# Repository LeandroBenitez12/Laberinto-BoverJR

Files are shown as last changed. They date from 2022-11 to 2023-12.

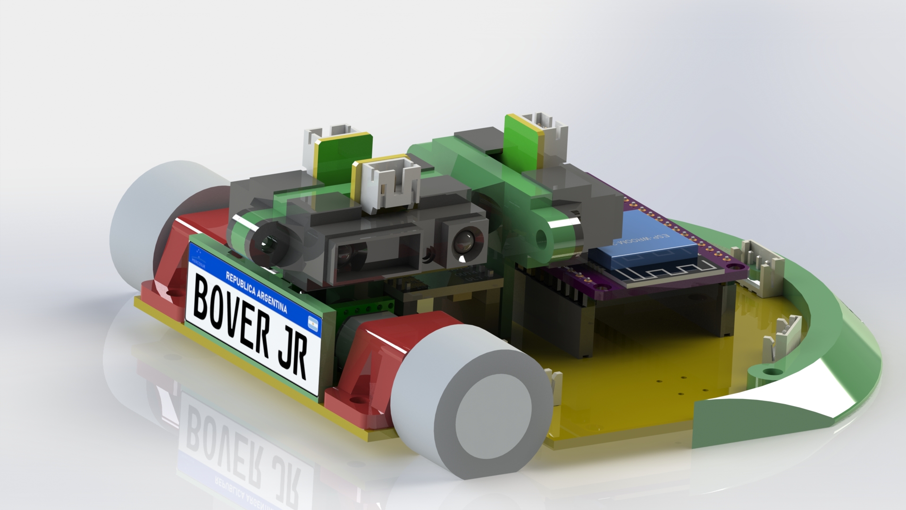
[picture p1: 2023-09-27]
Design 3D/2022 - Bover JR/RenderB.JPG

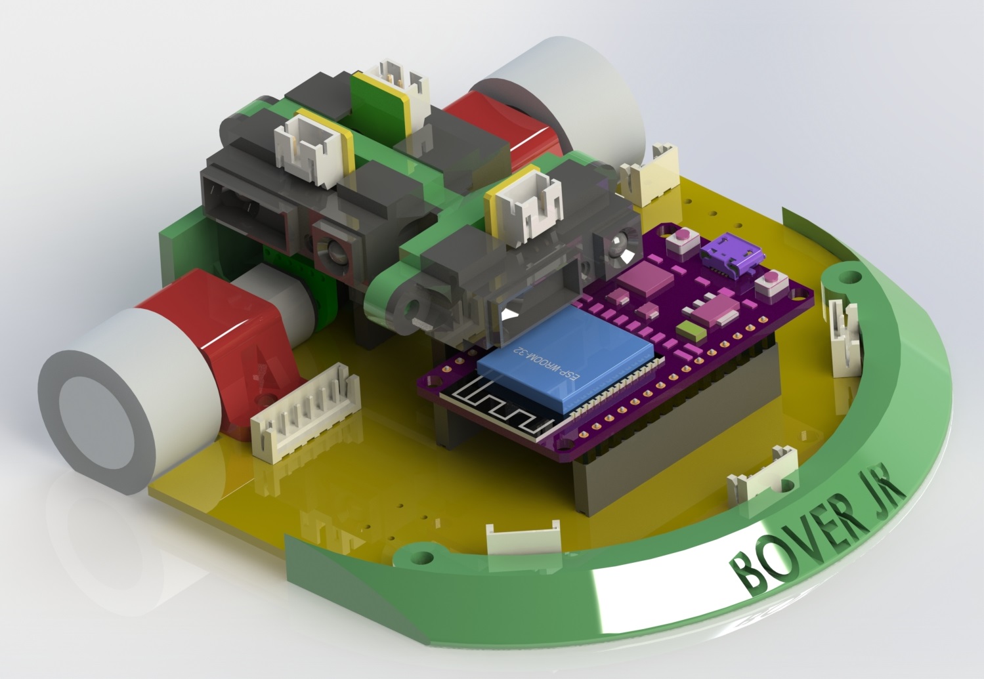
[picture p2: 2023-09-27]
Design 3D/2022 - Bover JR/Render.JPG

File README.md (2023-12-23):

# Robot en Desarrollo para la Resolución de Laberintos 🚧



Laberinto BoverJR 

<a href="https://www.pcbway.com/project/shareproject/Bover_JR_Maze_Robot_1de85bd7.html">PCB from PCBWay</a>

## Descripción del Proyecto

Este repositorio contiene el código y los recursos utilizados para el desarrollo de un robot resolvente de laberintos, creado por Leandro Benitez, Ezequiel Sierra iniciado en 2022 acompañado de nuestro Profesor Ing. Bustos Mariano en el "Industrial de Temperley" ,como parte de un emocionante proyecto para la resolución autónoma de laberintos y la participacion competitiva a nivel nacional en la LNR Argentina. Durante el proceso de creación, hemos estado trabajando arduamente para implementar algoritmos de búsqueda, controladores PID, y trabajar con sensores Sharp y la programación en un microcontrolador ESP32 con el entorno Arduino. También hemos diseñado y creado nuestras propias librerías específicas para el robot, además de experimentar con la utilización de máquinas de estados y Programación orientada a Objetos para lograr un funcionamiento eficiente y preciso.
Actualmente nos encontramos Sponsoreados por PCBWAY.COM donde diseñamos la nueva Version de Bover JR y esperamos competir durante 2023 y 2024 en la LNR , quiero agradecer a **PCBWAY** por financiar el PCB!!!

## Características del Proyecto en Desarrollo

- **Resolución autónoma de laberintos:** Estamos trabajando para permitir que el robot navegue y encuentre la salida de un laberinto sin intervención externa y en el menor tiempo posible.
- **Algoritmos de búsqueda:** Hemos comenzado a implementar diferentes algoritmos de búsqueda para dotar al robot de la capacidad de tomar decisiones inteligentes mientras explora el laberinto.
- **Controladores PID:** Utilizamos controladores PID para mejorar la precisión y estabilidad del robot al seguir una trayectoria y evitar desviaciones indeseadas.
- **Sensores Sharp:** Integración de sensores Sharp para detectar obstáculos y evitar colisiones durante el recorrido del laberinto.
- **ESP32 y Arduino:** El robot se basa en un ESP32 programado con el entorno Arduino, lo que nos brindó flexibilidad y recursos para desarrollar un sistema eficiente y la utilización de Bluetooth para debugear.
- **Librerías personalizadas:** Creamos librerías específicas para nuestro robot, lo que facilitó el manejo y organización del código.

## Estructura del Repositorio

- **/Software:** Aquí se encuentran los códigos que estuvimos trabajando en el laberinto con sus librerías.
- **/Design 3D:** Aqui se encuentran los 3D diseñados para el robot Bover JR 

## Cómo Contribuir

¡Valoramos cualquier contribución que puedas brindar para mejorar nuestro proyecto! Si deseas colaborar, sugerir mejoras o corregir problemas, sigue estos pasos:

1. Haz un fork de este repositorio y clona tu copia localmente.
2. Realiza los cambios y mejoras en tu rama, incluso si es para sugerir posibles soluciones o nuevas ideas.
3. Asegúrate de agregar o actualizar la documentación con tus contribuciones.
4. Realiza un pull request a nuestra rama principal para que podamos revisar y considerar tus aportes.

## Contacto

Nos encantaría recibir tus comentarios, sugerencias y cualquier tipo de feedback que nos ayude a mejorar nuestro proyecto. Si deseas ponerte en contacto con nosotros, no dudes en escribirnos a:

- Leandro Benitez: leandrobenitezz2004@gmail.com
- Empresa : bovergroup@gmail.com

## Sigue actualizado al proyecto siguiendonos en: 
<p align="left">
<a href="https://www.linkedin.com/in/leandro-benitez-995299211/" target="blank">leandrobenitez</a>
<a href="https://www.instagram.com/bovergroup/" target="blank">leandrobenitez</a>
<a href="https://www.tiktok.com/@bovergroup" target="blank">tiktok</a>
<a href="https://www.youtube.com/channel/UCQPRyj8CMgbOlkj3WffF_tw" target="blank">youtube</a>
</p>

## Agradecimientos

Queremos expresar nuestro agradecimiento a todas las personas que nos han brindado apoyo y colaboración en este proyecto, especialmente a **PCBWAY.COM** por sponsorear este proyecto. ¡Sin su ayuda, no habríamos llegado tan lejos en nuestro desarrollo!

Laberinto BoverJR
Laberinto BoverJR
Laberinto BoverJR
Laberinto BoverJR
Laberinto BoverJR




## Videos

https://github.com/LeandroBenitez12/Laberinto-BoverJR/assets/108737751/4792c012-6e11-466b-b290-4252d44b76c1

https://github.com/LeandroBenitez12/Laberinto-BoverJR/assets/108737751/9e88a07d-3f39-4b07-be96-34b641f0b9c9

https://github.com/LeandroBenitez12/Laberinto-BoverJR/assets/108737751/d4477cc3-5138-43af-baba-faa490c5ad7a

Estamos entusiasmados con los avances que hemos logrado hasta el momento, pero reconocemos que aún hay mucho trabajo por delante. Apreciamos tu comprensión y paciencia mientras continuamos mejorando y refinando nuestro robot resolvente de laberintos. Puedes seguir actualizado al proyecto siguiendonos en nuestras redes sociales:
🤖🏆

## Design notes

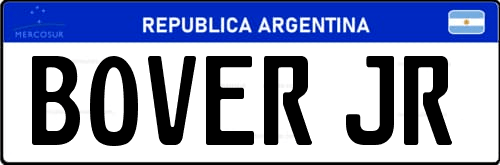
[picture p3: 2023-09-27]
Design 3D/2022 - Bover JR/gARG1.png

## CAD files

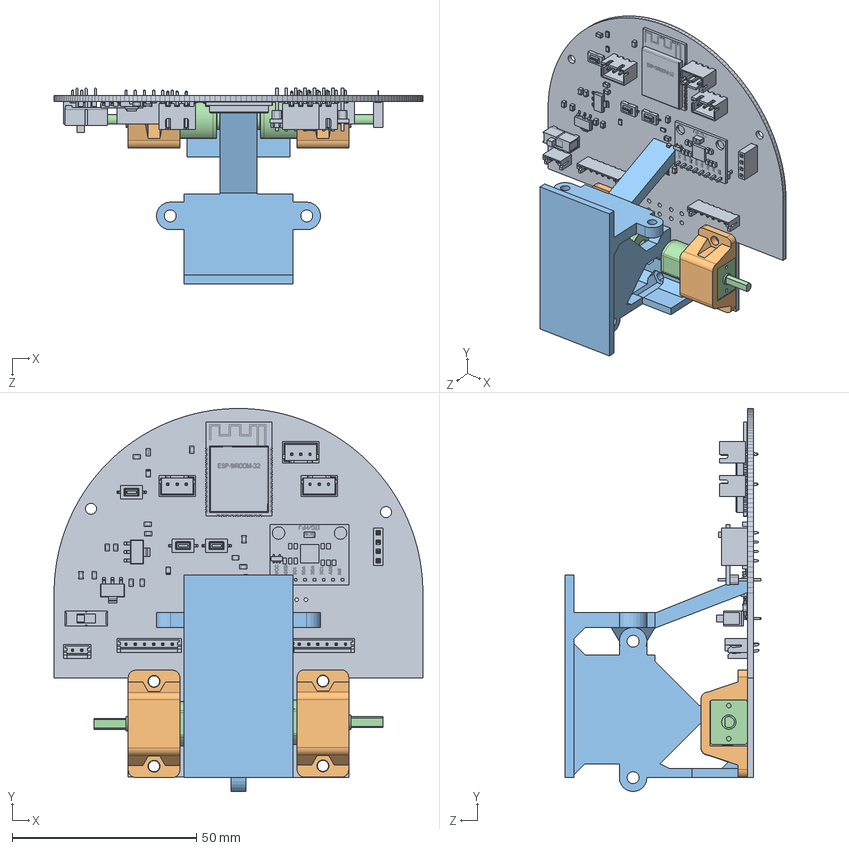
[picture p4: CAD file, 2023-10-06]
Design 3D/2023 - Bover JR/BoverJr_PCBWAY.SLDASM
100.0 x 103.8 x 53.2 mm
BoverJr_PCBWAY_pcb
Soporte_Motor_Pololu_negro_2023 x 2
Soporte_Sharp_Negro_2023
Micro-Motor-Pololu x 2

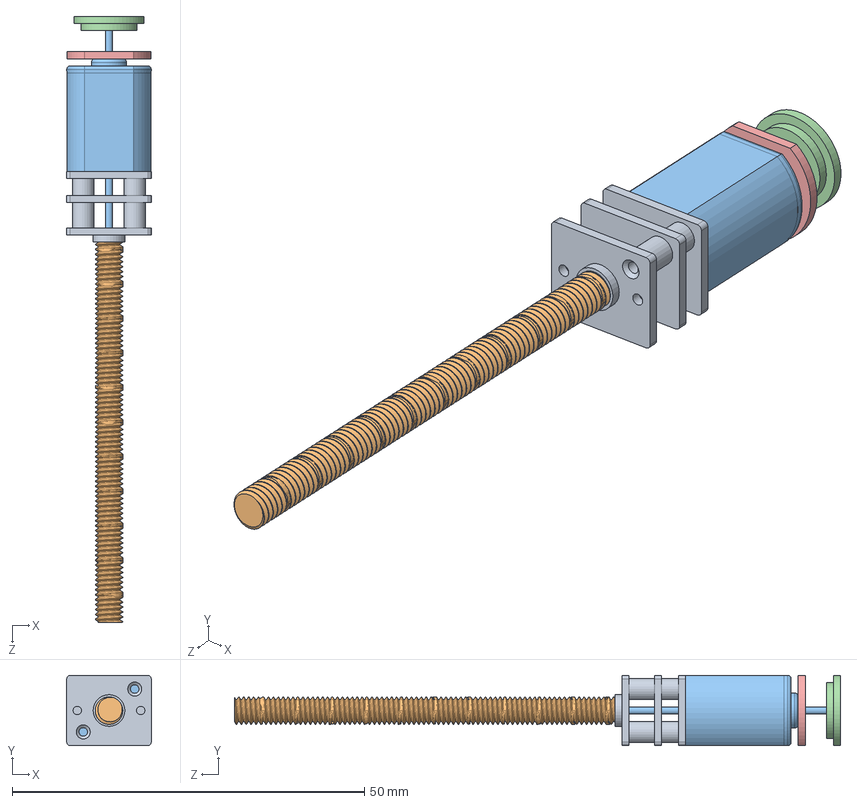
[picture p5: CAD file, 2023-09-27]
Design 3D/2022 - Bover JR/n20 encoder v2..SLDASM
12.0 x 10.0 x 86.0 mm
gearbox.step
threaded rod.step
n20 motor.step
magnet.step
encoder.step

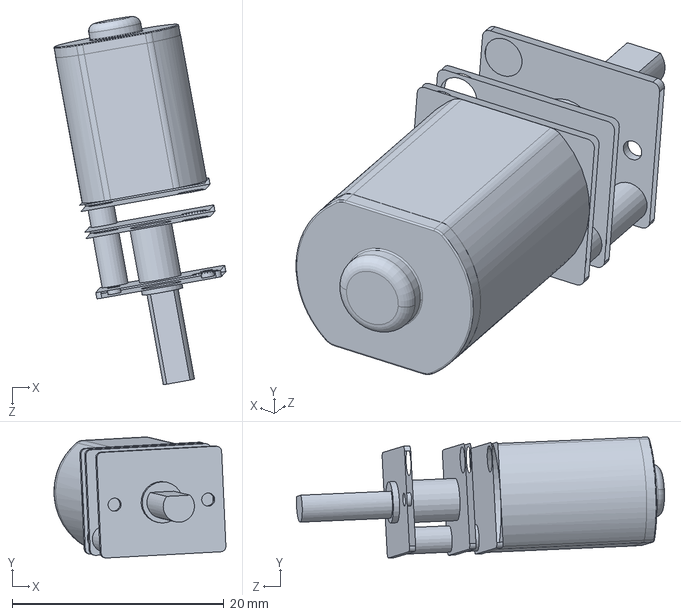
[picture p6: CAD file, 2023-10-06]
Design 3D/2022 - Bover JR/Micro-Motor-Pololu.SLDPRT
16.2 x 11.4 x 34.8 mm

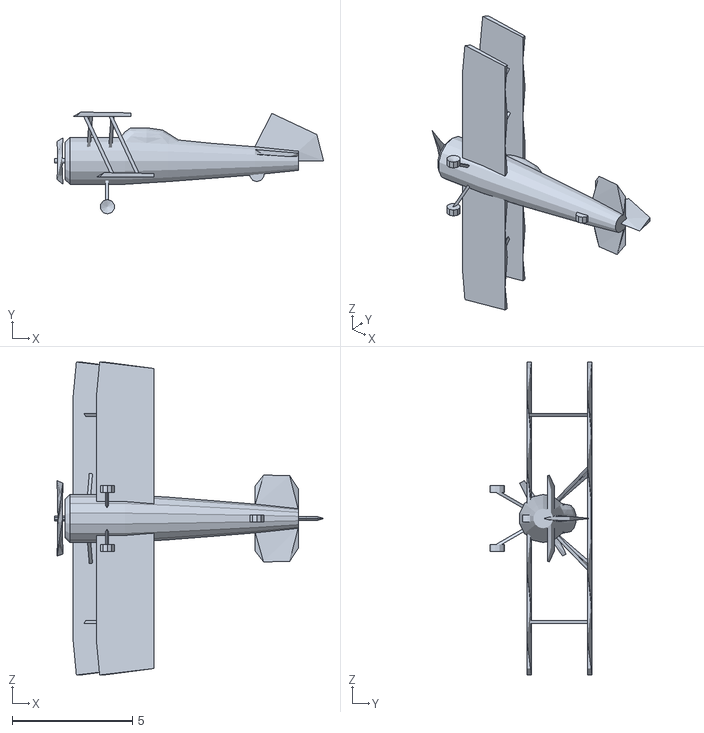
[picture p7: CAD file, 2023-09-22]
Software/Librerias/mpu6050-master/examples/MPU6050_DMP6_using_DMP_V6v12/MPUplane/data/biplane.obj
11.2 x 4.23 x 13.0

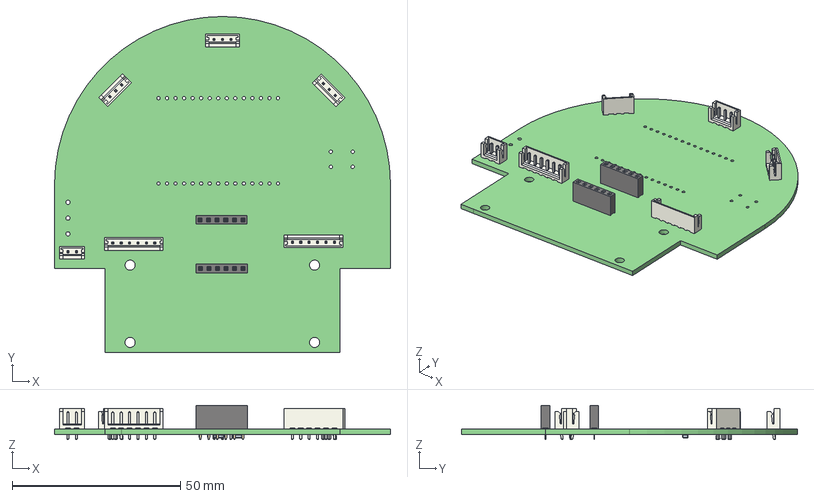
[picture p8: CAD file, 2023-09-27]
Design 3D/2022 - Bover JR/lab_V3.step
100.0 x 100.0 x 10.2 mm
lab_V3 PCB

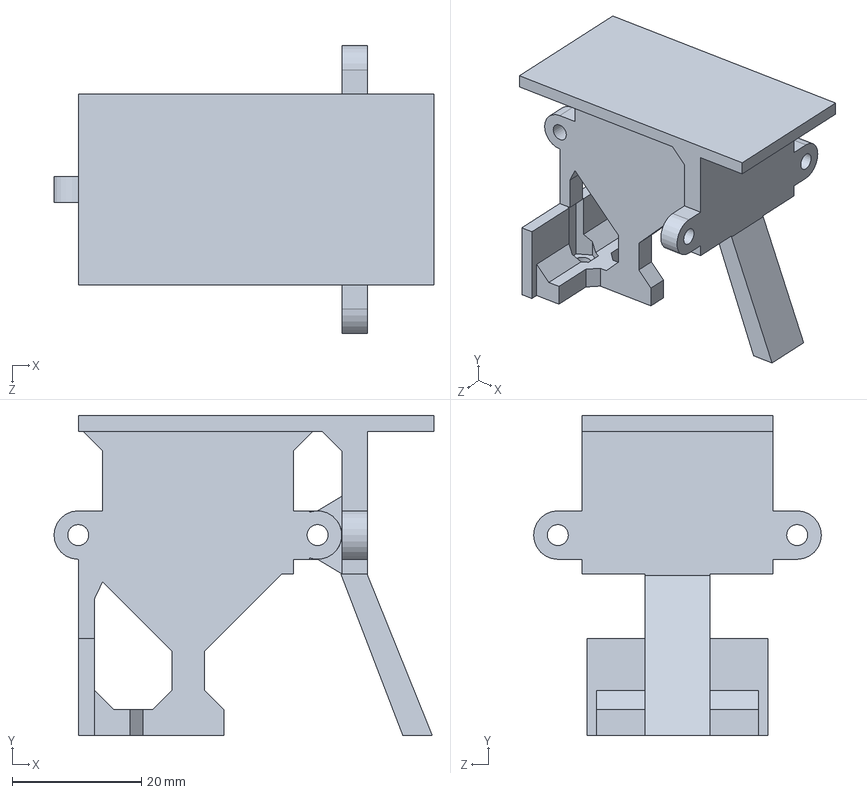
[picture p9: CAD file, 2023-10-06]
Design 3D/2023 - Bover JR/Soporte_Sharp_Negro_2023.SLDPRT
58.8 x 49.5 x 44.5 mm

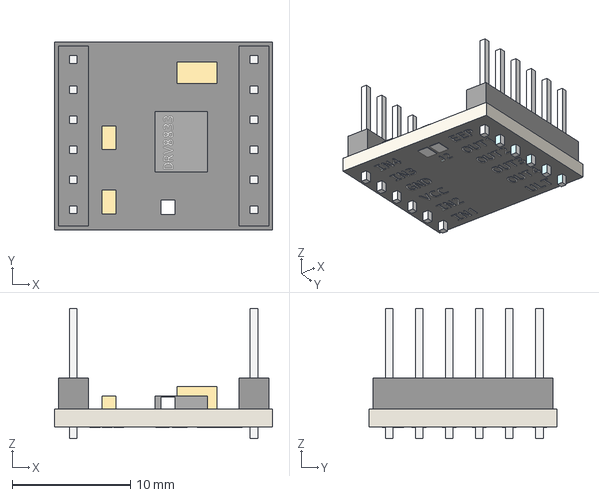
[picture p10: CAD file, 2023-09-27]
Design 3D/2022 - Bover JR/HBridgeDRV8833.step
18.4 x 15.9 x 11.0 mm

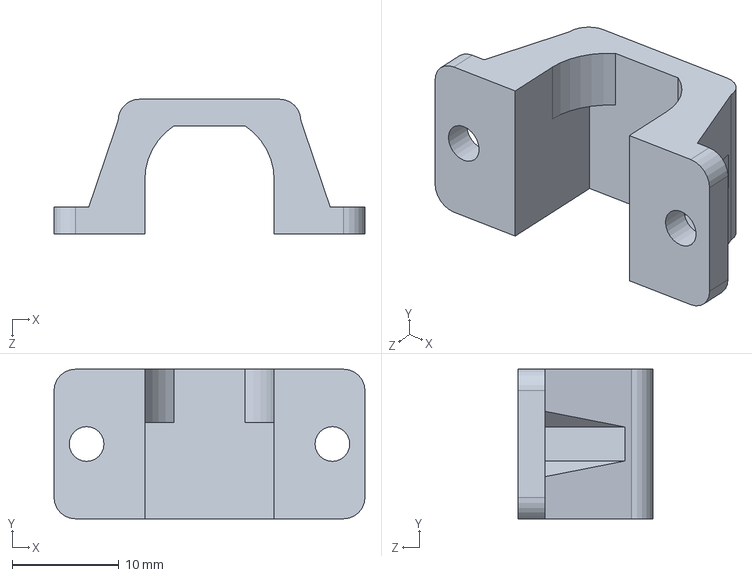
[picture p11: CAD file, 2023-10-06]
Design 3D/2023 - Bover JR/Soporte_Motor_Pololu_negro_2023.SLDPRT
29.1 x 14.0 x 12.6 mm

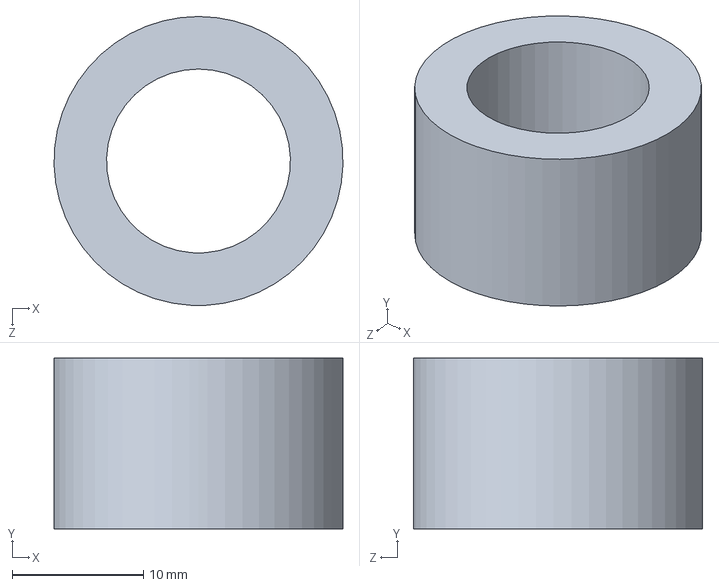
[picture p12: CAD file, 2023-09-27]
Design 3D/2022 - Bover JR/Cubierta_D22d14h13.SLDPRT
22.0 x 13.0 x 22.0 mm

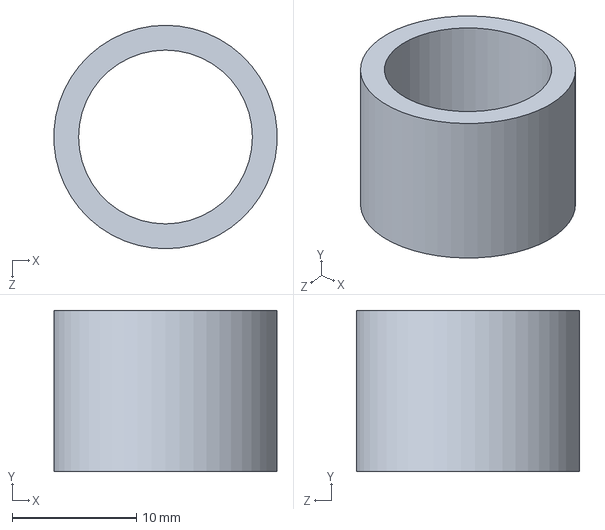
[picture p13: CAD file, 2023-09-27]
Design 3D/2022 - Bover JR/Cubierta_D18d14h13.SLDPRT
18.0 x 13.0 x 18.0 mm

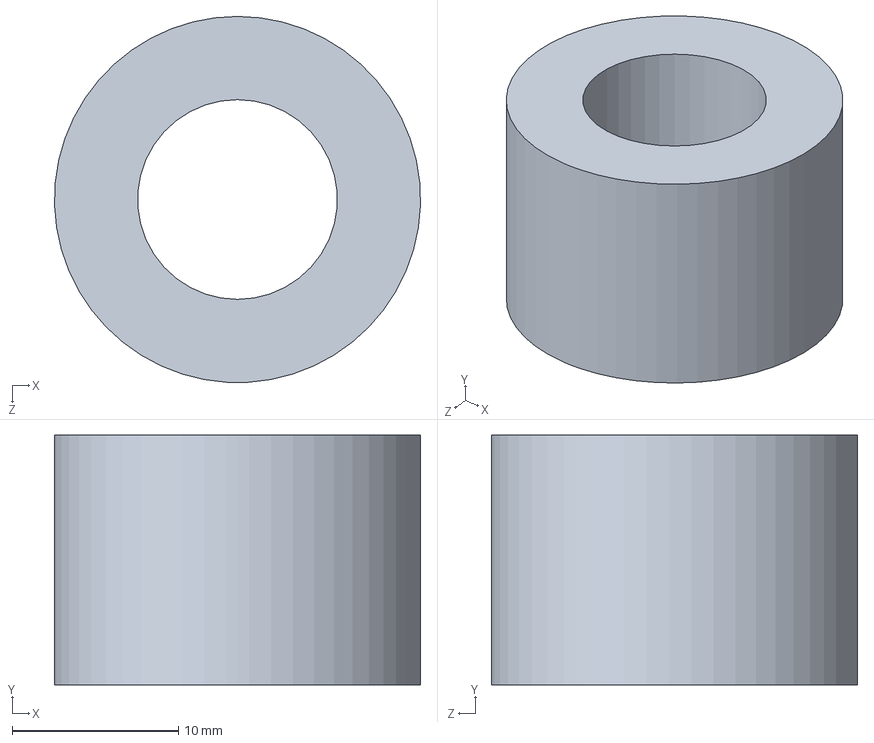
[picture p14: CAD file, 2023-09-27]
Design 3D/2022 - Bover JR/Cubierta.SLDPRT
22.0 x 15.0 x 22.0 mm

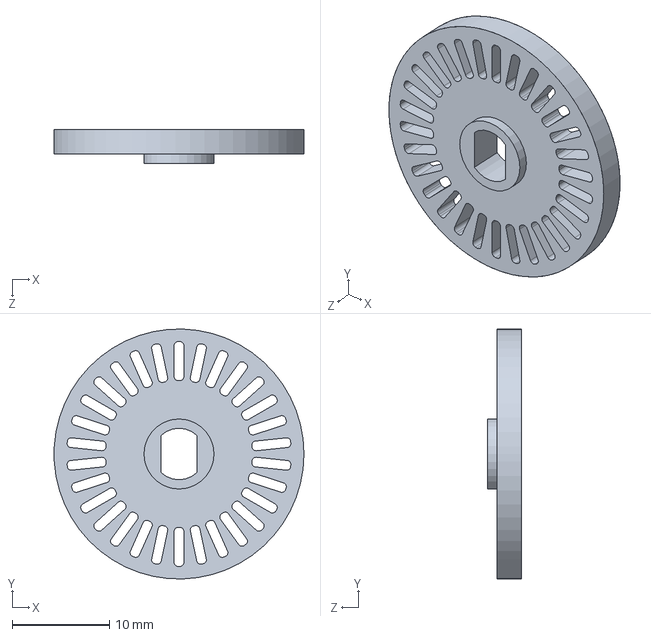
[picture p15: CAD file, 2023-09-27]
Design 3D/2022 - Bover JR/RuedaEncoder30Slot.SLDPRT
25.7 x 25.7 x 3.50 mm

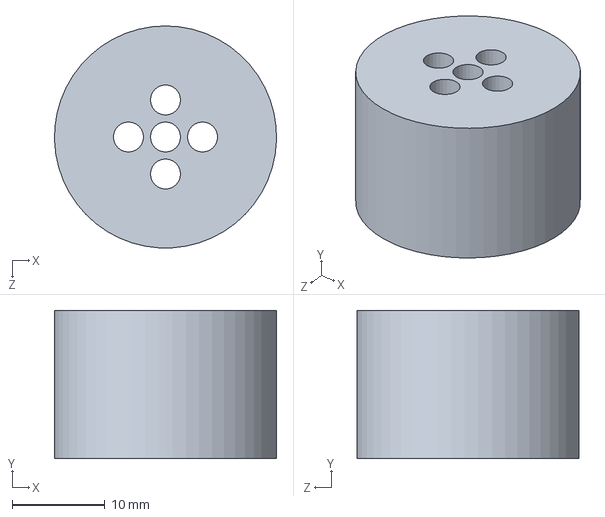
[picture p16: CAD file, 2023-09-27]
Design 3D/2022 - Bover JR/Molde_D22d14h13.SLDPRT
24.0 x 16.0 x 24.0 mm

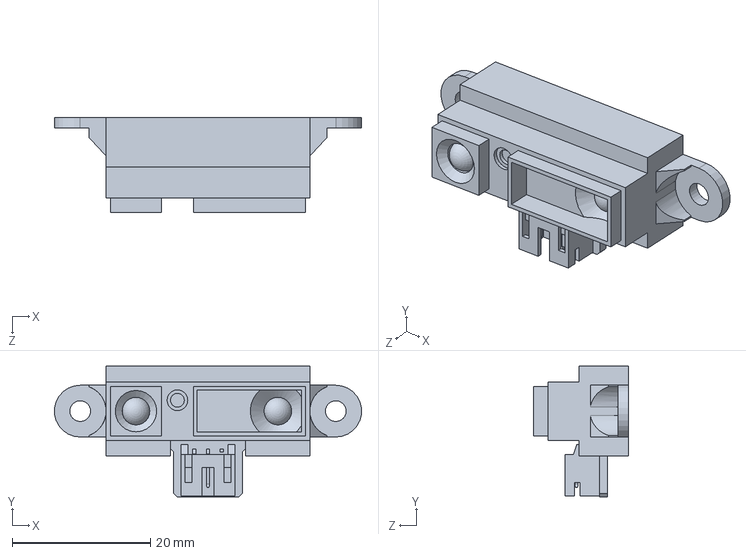
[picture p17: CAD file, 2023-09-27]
Design 3D/2022 - Bover JR/Sensor_Sharp_Corto.SLDPRT
44.4 x 18.9 x 13.7 mm

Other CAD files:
Design 3D/2022 - Bover JR/Soporte_Motor_Pololu.SLDPRT
Design 3D/2022 - Bover JR/Pololu Magnetic Encoder.SLDPRT
Design 3D/2022 - Bover JR/Llanta_3D_V2.SLDPRT
Design 3D/2022 - Bover JR/ESP_32_30Pins.SLDPRT
Design 3D/2022 - Bover JR/Llanta_MiniSumoV1.SLDPRT
Design 3D/2022 - Bover JR/Molde_D22d14h13.STL
Design 3D/2022 - Bover JR/Pololu Magnetic Encoder #1523.SLDPRT
Design 3D/2022 - Bover JR/RuedaEncoder30Slot.STL
Design 3D/2022 - Bover JR/SoporteSharps.SLDPRT
Design 3D/2022 - Bover JR/SoporteSharps.STL
Design 3D/2022 - Bover JR/Soporte_Motor_Pololu.STL
Design 3D/2022 - Bover JR/lab_V3.SLDASM
Design 3D/2022 - Bover JR/n20 encoder v2.SLDPRT
Design 3D/2022 - Bover JR/soporte_piso.SLDPRT
Design 3D/2023 - Bover JR/Soporte_Motor_Pololu_negro_2023.STL
Design 3D/2023 - Bover JR/Soporte_Sharp_Negro_2023.STL

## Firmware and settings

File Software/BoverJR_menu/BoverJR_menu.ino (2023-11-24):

// libreries
#include <PID.h>
#include <EngineController.h>
#include <DistanceSensors.h>
#include <Button.h>
#include "BluetoothSerial.h"
#include "I2Cdev.h"
#include "MPU6050_6Axis_MotionApps20.h"

// I2C
#if I2CDEV_IMPLEMENTATION == I2CDEV_ARDUINO_WIRE
#include "Wire.h"
#endif

// BLUETOOH
#if !defined(CONFIG_BT_ENABLED) || !defined(CONFIG_BLUEDROID_ENABLED)
#error Bluetooth is not enabled! Please run `make menuconfig` to and enable it
#endif
BluetoothSerial SerialBT;

// DEBUG
#define DEBUG_BUTTON 0
#define DEBUG_STATUS 0
#define DEBUG_SENSORS 0
#define DEBUG_PID 0
#define DEBUG_EJE_Z 0
// TICKS DEBUG
#define TICK_DEBUG_ALL 500
unsigned long currentTimeDebugAll = 0;

// PINOUT
// Motores
#define PIN_RIGHT_ENGINE_IN1 27
#define PIN_RIGHT_ENGINE_IN2 26
#define PIN_LEFT_ENGINE_IN1 19
#define PIN_LEFT_ENGINE_IN2 18
#define PWM_CHANNEL_RIGHT_IN1 1
#define PWM_CHANNEL_RIGHT_IN2 2
#define PWM_CHANNEL_LEFT_IN1 3
#define PWM_CHANNEL_LEFT_IN2 4

// Sharps
#define PIN_SHARP_RIGHT 25
#define PIN_SHARP_LEFT 35
#define PIN_SHARP_FRONT 33
float rightDistance;
float leftDistance;
float frontDistance;
#define PARED_ENFRENTE 10
#define PARED_COSTADO_PASILLO 18
#define NO_HAY_PARED 24
#define NO_HAY_PARED_ENFRENTE 24

// MPU
#define INTERRUPT_PIN 4
#define MARGEN 5
#define POSITIVE_ANGLE_MAX 180
#define RIGHT_LIMIT_NEG -180
unsigned long currentTimewhileZ;
float gyroZ;

// Boton
#define PIN_BUTTON_START 32
bool stateStartButton = 0;

// MENU variables
#define VALUE_5 5     // valor 5 para aumentar/disminuir velocidad
#define VALUE_0_1 0.1 // valor 0.1 para aumentar/disminuir PID
bool parar_motores = false;
bool iniciarRobot = false;
bool walltofollow = false;
unsigned long currentTimeMenu = 0;

// veocidades motores pwm
#define SPEED_TURN_LOW 90
#define ENTRAR_EN_PASILLO 300
#define OMITIR_BIFURCACION 600
#define MAX_SPEED 255
int averageSpeedRight = 140; // velocidad inicial
int averageSpeedLeft = 150;  // velocidad inicial + 10
int speedRightPID;
int speedLeftPID;
int speedRightPID2;
int speedLeftPID2;

// Constantes y variables pid
unsigned long currentTimePID = 0;
#define TICK_PID 1
double kp = 3;
double kd = 0.6;
double ki = 0.0;
double setPoint = 0.0;
double gananciaPID = 0;
double input = 0;

// variables pid2
double kp2 = 0;
double kd2 = 0;
double ki2 = 0.0;
double setPoint2 = 0;
double gananciaPID2;
double TICK_PID2 = 1.0;

unsigned long currentTimeStop = 0;
#define TICK_STOP 1000
#define TICK_CENTRAR 500
// enum state
enum movement
{
  STANDBY,
  CONTINUE,
  STOP,
  RIGHT_TURN,
  LEFT_TURN,
  FULL_TURN,
  POST_TURN_FULL,
  POST_TURN_MIDDLE,
  ANT_TURN
};
int movement = STANDBY;

// INSTANCIANDO OBJETOS
IEngine *leftEngine = new Driver_DRV8825(PIN_RIGHT_ENGINE_IN1, PIN_RIGHT_ENGINE_IN2, PWM_CHANNEL_RIGHT_IN1, PWM_CHANNEL_RIGHT_IN2);
IEngine *rightEngine = new Driver_DRV8825(PIN_LEFT_ENGINE_IN1, PIN_LEFT_ENGINE_IN2, PWM_CHANNEL_LEFT_IN1, PWM_CHANNEL_LEFT_IN2);
EngineController *Bover = new EngineController(rightEngine, leftEngine);
Isensor *SharpRight = new Sharp_GP2Y0A21(PIN_SHARP_RIGHT);
Isensor *SharpLeft = new Sharp_GP2Y0A21(PIN_SHARP_LEFT);
Isensor *SharpFront = new Sharp_GP2Y0A21(PIN_SHARP_FRONT);
Pid *PID = new Pid(kp, kd, ki, setPoint, TICK_PID);
Pid *PID2 = new Pid(kp2, kd2, ki2, setPoint2, TICK_PID2);
Button *buttonStart1 = new Button(PIN_BUTTON_START);
MPU6050 mpu;

// MPU control/status vars
bool dmpReady = false;  // set true if DMP init was successful
uint8_t mpuIntStatus;   // holds actual interrupt status byte from MPU
uint8_t devStatus;      // return status after each device operation (0 = success, !0 = error)
uint16_t packetSize;    // expected DMP packet size (default is 42 bytes)
uint16_t fifoCount;     // count of all bytes currently in FIFO
uint8_t fifoBuffer[64]; // FIFO storage buffer
Quaternion q;           // [w, x, y, z]
VectorInt16 aa;         // [x, y, z]
VectorInt16 aaReal;     // [x, y, z]
VectorInt16 aaWorld;    // [x, y, z]
VectorFloat gravity;    // [x, y, z]
float ypr[3];           // [yaw, pitch, roll]
volatile bool mpuInterrupt = false;

void dmpDataReady()
{
  mpuInterrupt = true;
}

void mpuSetup()
{
// join I2C bus (I2Cdev library doesn't do this automatically)
#if I2CDEV_IMPLEMENTATION == I2CDEV_ARDUINO_WIRE
  Wire.begin();
  Wire.setClock(400000); // 400kHz I2C clock. Comment this line if having compilation difficulties
#elif I2CDEV_IMPLEMENTATION == I2CDEV_BUILTIN_FASTWIRE
  Fastwire::setup(400, true);
#endif

  // Iniciar MPU6050
  SerialBT.println(F("Initializing I2C devices..."));
  mpu.initialize();
  pinMode(INTERRUPT_PIN, INPUT);

  // Comprobar  conexion
  SerialBT.println(F("Testing device connections..."));
  SerialBT.println(mpu.testConnection() ? F("MPU6050 connection successful") : F("MPU6050 connection failed"));

  // Iniciar DMP
  SerialBT.println(F("Initializing DMP..."));
  devStatus = mpu.dmpInitialize();

  // Valores de calibracion
  mpu.setXGyroOffset(60);
  mpu.setYGyroOffset(49);
  mpu.setZGyroOffset(-69);
  mpu.setZAccelOffset(1046);

  // Activar DMP
  if (devStatus == 0)
  {
    SerialBT.println(F("Enabling DMP..."));
    mpu.setDMPEnabled(true);

    // Activar interrupcion
    attachInterrupt(digitalPinToInterrupt(INTERRUPT_PIN), dmpDataReady, RISING);
    mpuIntStatus = mpu.getIntStatus();

    SerialBT.println(F("DMP ready! Waiting for first interrupt..."));
    dmpReady = true;

    // get expected DMP packet size for later comparison
    packetSize = mpu.dmpGetFIFOPacketSize();
  }
  else
  {
    // ERROR!
    // 1 = initial memory load failed
    // 2 = DMP configuration updates failed
    // (if it's going to break, usually the code will be 1)
    SerialBT.print(F("DMP Initialization failed (code "));
    SerialBT.print(devStatus);
    SerialBT.println(F(")"));
  }
}
// MPU LOOP
float mpuLoop()
{
  // Si fallo al iniciar, parar programa
  // if (!dmpReady)
  // return;
  // Ejecutar mientras no hay interrupcion
  while (!mpuInterrupt && fifoCount < packetSize)
  {
  // AQUI EL RESTO DEL CODIGO DE TU PROGRRAMA
  }
  mpuInterrupt = false;
  mpuIntStatus = mpu.getIntStatus();

  // Obtener datos del FIFO
  fifoCount = mpu.getFIFOCount();

  // Controlar overflow
  if ((mpuIntStatus & 0x10) || fifoCount == 4096)
  {
    mpu.resetFIFO();
    // SerialBT.println(F("FIFO overflow!"));
  }
  else if (mpuIntStatus & 0x02)
  {
    // wait for correct available data length, should be a VERY short wait
    while (fifoCount < packetSize)
      fifoCount = mpu.getFIFOCount();

    // read a packet from FIFO
    mpu.getFIFOBytes(fifoBuffer, packetSize);

    // track FIFO count here in case there is > 1 packet available
    // (this lets us immediately read more without waiting for an interrupt)
    fifoCount -= packetSize;

    // MMostrar Yaw, Pitch, Roll
    mpu.dmpGetQuaternion(&q, fifoBuffer);
    mpu.dmpGetGravity(&gravity, &q);
    mpu.dmpGetYawPitchRoll(ypr, &q, &gravity);
    float gz;
    return gz = ypr[0] * 180 / M_PI;
    delay(1);
  }
}
// LECTURA SENSORS
void SensorsRead()
{
  frontDistance = SharpFront->SensorRead();
  rightDistance = SharpRight->SensorRead();
  leftDistance = SharpLeft->SensorRead();
}

// IMPRIMIR EN BLUETOOH
void printButton()
{
  SerialBT.print("Button Start: ");
  SerialBT.println(stateStartButton);
}

void printPID()
{
  if (millis() > currentTimePID + TICK_DEBUG_ALL)
  {
    currentTimePID = millis();
    SerialBT.println("");
    SerialBT.print("Ganancia PID 1: ");
    SerialBT.println(gananciaPID);
    // SerialBT.print("Ganancia PID 2: ");
    // SerialBT.println(gananciaPID2);
    SerialBT.print("speedRight: ");
    SerialBT.print(speedRightPID);
    SerialBT.print(" || speedLeft: ");
    SerialBT.println(speedLeftPID);
    SerialBT.println("");
  }
}

void printEjeZ()
{
  SerialBT.print("Eje Z:  ");
  SerialBT.print(gyroZ);
}

void printSensors()
{
  SerialBT.print("LeftDistance: ");
  SerialBT.println(leftDistance);
  SerialBT.print("frontDistance: ");
  SerialBT.println(frontDistance);
  SerialBT.print(" || rightDistance: ");
  SerialBT.println(rightDistance);
}

void printOptions()
{
  // clean the serial
  for (int i = 0; i < 5; i++)
  {
    SerialBT.println("");
  }
  SerialBT.println("Configuracion Actual:");

  SerialBT.print("A+/B- KP = ");
  SerialBT.println(kp);

  SerialBT.print("C+/D- KP2 = ");
  SerialBT.println(kp2);

  SerialBT.print("E+/F- KD = ");
  SerialBT.println(kd);

  SerialBT.print("G+/H- KD2 = ");
  SerialBT.println(kd2);

  SerialBT.print("I+/J- - leftSpeed = ");
  SerialBT.println(averageSpeedLeft);

  SerialBT.print("K+/L- - rightLeft = ");
  SerialBT.println(averageSpeedRight);

  SerialBT.print("N - Wall to follow = ");
  String state = "";
  if (walltofollow == true)
    state = "Right";
  else
    state = "Left";
  SerialBT.println(state);

  SerialBT.print("P - Motor parado = ");
  SerialBT.println(parar_motores);

  SerialBT.println("Y - DEBUGEAR ROBOT ");

  SerialBT.println("Z - INICIAR ROBOT ");

  for (int i = 0; i < 5; i++)
  {
    SerialBT.println("");
  }
}
// GIROS 90º Y 180º
void turnRight()
{
  SerialBT.println("  entro right  ");
  do
  {
    SensorsRead();
    Bover->Right(SPEED_TURN_LOW, SPEED_TURN_LOW);
  } while ( frontDistance < 28);
  SerialBT.println("  sali right  ");
  movement = POST_TURN_MIDDLE;
}

void turnLeft()
{
  SerialBT.println("  entro left  ");
  do
  {
    SensorsRead();
    Bover->Left(SPEED_TURN_LOW, SPEED_TURN_LOW);
  } while ( frontDistance < 28);
  SerialBT.println("  sali left  ");
  movement = POST_TURN_MIDDLE;
}

void fullTurn()
{
  SerialBT.println("  entro full  ");
  do
  {
    SensorsRead();
    Bover->Right(SPEED_TURN_LOW, SPEED_TURN_LOW);
  } while ( frontDistance < 28);
  SerialBT.println("  sali FULL  ");
  movement = CONTINUE;
}

void postTurnFull()
{
  Bover->Forward(averageSpeedRight, averageSpeedLeft);
  delay(OMITIR_BIFURCACION);
}
void postTurnMiddle()
{
  Bover->Forward(averageSpeedRight, averageSpeedLeft);
  delay(ENTRAR_EN_PASILLO);
}

void antTurn()
{
  Bover->Forward(averageSpeedRight, averageSpeedLeft);
  delay(TICK_CENTRAR);
}

void menuBT()
{
  if (SerialBT.available())
  {
    char option = SerialBT.read();
    switch (option)
    {
    case 'M':
    {
      printOptions();
      break;
    }
    case 'A':
    {
      kp += VALUE_0_1;
      SerialBT.println("");
      printOptions();
      SerialBT.println("");
      break;
    }
    case 'B':
    {
      kp -= VALUE_0_1;
      SerialBT.println("");
      printOptions();
      SerialBT.println("");
      break;
    }
    case 'C':
    {
      kp2 += VALUE_0_1;
      SerialBT.println("");
      printOptions();
      SerialBT.println("");
      break;
    }
    case 'D':
    {
      kp2 -= VALUE_0_1;
      SerialBT.println("");
      printOptions();
      SerialBT.println("");
      break;
    }
    case 'E':
    {
      kd += VALUE_0_1;
      SerialBT.println("");
      printOptions();
      SerialBT.println("");
      break;
    }
    case 'F':
    {
      kd -= VALUE_0_1;
      SerialBT.println("");
      printOptions();
      SerialBT.println("");
      break;
    }
    case 'G':
    {
      kd2 += VALUE_0_1;
      SerialBT.println("");
      printOptions();
      SerialBT.println("");
      break;
    }
    case 'H':
    {
      kd2 -= VALUE_0_1;
      SerialBT.println("");
      printOptions();
      SerialBT.println("");
      break;
    }
    case 'I':
    {
      averageSpeedLeft = averageSpeedLeft + VALUE_5;

      SerialBT.println("");
      printOptions();
      SerialBT.println("");
      break;
    }
    case 'J':
    {
      averageSpeedLeft = averageSpeedLeft - VALUE_5;
      SerialBT.println("");
      printOptions();
      SerialBT.println("");
      break;
    }
    case 'K':
    {
      averageSpeedRight = averageSpeedRight + VALUE_5;
      SerialBT.println("");
      printOptions();
      SerialBT.println("");
      break;
    }

    case 'L':
    {
      averageSpeedRight -= VALUE_5;
      SerialBT.println("");
      printOptions();
      SerialBT.println("");
      break;
    }
    case 'N':
    {
      walltofollow = true;

      SerialBT.println("");
      printOptions();
      SerialBT.println("");
      break;
    }
    case 'P':
    {
      parar_motores = true;

      SerialBT.println("");
      printOptions();
      SerialBT.println("");
      break;
    }
    case 'Z':
    {
      stateStartButton = true;
      SerialBT.println("");
      printOptions();
      SerialBT.println("");
      break;
    }
    default:
      SerialBT.println("OPCION INCORRECTA ");
      break;
    }
  }
}

void movementLogic()
{
  switch (movement)
  {
  case STANDBY:
  {
    Bover->Stop();
    if (stateStartButton)
    {
      delay(2000);
      movement = CONTINUE;
    }
  }
  break;
  case CONTINUE:
  {
    //float input = leftDistance;
    //if (walltofollow)
    //  input = rightDistance;

    input = rightDistance - leftDistance;
    gananciaPID = PID->ComputePid(input);
    // gananciaPID2 = PID2->ComputePid(input2);
    //  INPUT2 = WALLTOFOLLOW PARA MANTENER LA DISTANCIA A ESA PARED
    //  float input2 = leftDistance;
    //  if (walltofollow == true)
    //  input2 = rightDistance;
    //  gananciaPID2 = PID2->ComputePid(input2);

    if (DEBUG_PID)
      printPID();

    speedRightPID = (averageSpeedRight - (gananciaPID));
    speedLeftPID = (averageSpeedLeft + (gananciaPID));

    // APLICAMOS GANANCIA 1 DEL PID A MOTORES. okey
    // if (walltofollow)
    // {
    //   speedRightPID = (averageSpeedRight - (gananciaPID));
    //   speedLeftPID = (averageSpeedLeft + (gananciaPID));
    // }
    // else
    // {
    //   speedRightPID = (averageSpeedRight + (gananciaPID));
    //   speedLeftPID = (averageSpeedLeft - (gananciaPID));
    // }
    // APLICAMOS GANANCIA 2 DEL PID A MOTORES
    // speedRightPID2 = (speedRightPID + (gananciaPID2));
    // speedLeftPID2 = (speedLeftPID - (gananciaPID2));

    // ESTABLECEMOS LOS LIMITES
    if (speedLeftPID > MAX_SPEED)
    {
      int umbralLeft = (speedLeftPID - MAX_SPEED);
      speedRightPID = speedRightPID - umbralLeft;
      speedLeftPID = MAX_SPEED;
    }

    if (speedRightPID > MAX_SPEED)
    {
      int umbralRight = (speedRightPID - MAX_SPEED);
      speedLeftPID = speedLeftPID - umbralRight;
      speedRightPID = MAX_SPEED;
    }

    if (parar_motores)
    {
      Bover->Stop();
    }
    else
    {
      Bover->Forward(speedRightPID, speedLeftPID);
    }

    if (walltofollow == true)
    {
      if (leftDistance > NO_HAY_PARED && frontDistance > NO_HAY_PARED_ENFRENTE && rightDistance > NO_HAY_PARED)
      {
        movement = ANT_TURN;
      }
      if (leftDistance <= PARED_COSTADO_PASILLO && frontDistance > NO_HAY_PARED_ENFRENTE && rightDistance > NO_HAY_PARED)
      {
        movement = ANT_TURN;
      }
      if (leftDistance > NO_HAY_PARED && frontDistance > NO_HAY_PARED_ENFRENTE && rightDistance <= PARED_COSTADO_PASILLO)
      {
        movement = POST_TURN_FULL;
      }
    }
    else
    {
      if (leftDistance > NO_HAY_PARED && frontDistance > NO_HAY_PARED_ENFRENTE && rightDistance > NO_HAY_PARED)
      {
        movement = ANT_TURN;
      }
      if (leftDistance > NO_HAY_PARED && frontDistance > NO_HAY_PARED_ENFRENTE && rightDistance <= PARED_COSTADO_PASILLO)
      {
        movement = ANT_TURN;
      }
      if (leftDistance <= PARED_COSTADO_PASILLO && frontDistance > NO_HAY_PARED_ENFRENTE && rightDistance > NO_HAY_PARED)
      {
        movement = POST_TURN_FULL;
      }
    }
    if (frontDistance <= PARED_ENFRENTE)
    {
      movement = STOP;
    }
    break;
  }
  case STOP:
  {
    Bover->Stop();
    delay(500);
    if (frontDistance <= PARED_ENFRENTE)
    {
      if (rightDistance > NO_HAY_PARED && leftDistance > NO_HAY_PARED)
      {
        if (walltofollow = true)
        {
          movement = RIGHT_TURN;
        }
        else
        {
          movement = LEFT_TURN;
        }
      }
      else if (rightDistance <= PARED_COSTADO_PASILLO && leftDistance <= PARED_COSTADO_PASILLO)
      {
        movement = FULL_TURN;
      }
      else if (rightDistance > NO_HAY_PARED && leftDistance <= PARED_COSTADO_PASILLO)
      {
        movement = RIGHT_TURN;
      }
      else if (rightDistance <= PARED_COSTADO_PASILLO && leftDistance > NO_HAY_PARED)
      {
        movement = LEFT_TURN;
      }
    }
    else
    {
      movement = CONTINUE;
    }
    break;
  }

  case RIGHT_TURN:
  {
    turnRight();
    break;
  }

  case LEFT_TURN:
  {
    turnLeft();
    break;
  }

  case FULL_TURN:
  {
    fullTurn();
    break;
  }

  case POST_TURN_MIDDLE:
  {
    postTurnMiddle();
    movement = CONTINUE;
    break;
  }

  case POST_TURN_FULL:
  {
    postTurnFull();
    movement = CONTINUE;
    break;
  }
  case ANT_TURN:
  {
    antTurn();
    if (walltofollow == true)
    {
      movement = RIGHT_TURN;
    }
    else
    {
      movement = LEFT_TURN;
    }
  }
  }
}

void printStatus()
{
  String state = "";
  switch (movement)
  {
  case STANDBY:
    state = "STANDBY";
    break;
  case CONTINUE:
    state = "CONTINUE";
    break;
  case STOP:
    state = state = "STOP";
    break;
  case RIGHT_TURN:
    state = "RIGHT TURN";
    break;
  case LEFT_TURN:
    state = "LEFT TURN";
    break;
  case FULL_TURN:
    state = "FULL TURN";
    break;
  case POST_TURN_MIDDLE:
    state = "POST TURN MIDDLE";
    break;
  case POST_TURN_FULL:
    state = "POST TURN FULL";
    break;
  case ANT_TURN:
    state = "ANT TURN ";
    break;
  }
  SerialBT.print("State: ");
  SerialBT.println(state);
}

void printAll()
{
  if (millis() > currentTimeDebugAll + TICK_DEBUG_ALL)
  {
    currentTimeDebugAll = millis();
    if (DEBUG_BUTTON)
      printButton();
    SerialBT.println("");
    if (DEBUG_SENSORS)
      printSensors();
    SerialBT.println("");
    if (DEBUG_STATUS)
      printStatus();
    SerialBT.println("");
    if (DEBUG_EJE_Z)
      printEjeZ();
    SerialBT.println("");
  }
}
void setup()
{
  Serial.begin(115200);
  SerialBT.begin("Bover JR");
  mpuSetup();
}

void loop()
{
  gyroZ = mpuLoop();
  stateStartButton = buttonStart1->GetIsPress();
  SensorsRead();
  if (iniciarRobot == false)
  {
    menuBT();
  }
  if (stateStartButton == true)
  {
    iniciarRobot = true;
  }
  if (iniciarRobot == true)
  {
    movementLogic();
    printAll();
  }
}

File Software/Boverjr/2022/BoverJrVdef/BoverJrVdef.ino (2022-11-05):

#include <PID.h>
#include <Engine.h>
#include <Button.h>
#include <QRE1113.h>
#include <SharpLab.h>
#include "BluetoothSerial.h"


//debug
#define DEBUG 1
#define TICK_DEBUG 400
unsigned long currentTimeDebug = 0;
unsigned long currentTimeDebugSensors = 0;
unsigned long currentTimeDebugPID = 0;

// declaramos pines
// motores
#define PIN_ENGINE_MR1 23
#define PIN_ENGINE_MR2 22
#define PIN_ENGINE_ML1 19
#define PIN_ENGINE_ML2 18

// Button
#define PIN_BUTTON_START 39
bool button_start;

//Sensor final
#define PIN_END_SENSOR 32

//Sharps
#define PIN_SHARP_RIGHT 34
#define PIN_SHARP_LEFT 27
#define PIN_SHARP_FRONT 35
float frontDistance;
float rightDistance;
float leftDistance;
#define MAX_FRONT_DISTANCE 20
#define MAX_SIDE_DISTANCE 12

//encoder 
int interruptPinRight = 26;
int interruptPinLeft = 21;
volatile long rightCont = 0;
volatile long leftCont = 0;
#define TICK_TURN_RIGHT_90 17
#define TICK_TURN_LEFT_90 120
#define TICK_TURN_180 34
#define TICK_POST_TURN 37
#define TICK_ANT_TURN 30
#define TICK_IGNORE_TURN 40

void rightEncRead()
{
    rightCont++;
}

void leftEncRead()
{
    leftCont++;
}

//veocidades motores pwm
int speedRight = 80;
int speedLeft = 80;
int averageSpeed = 80;
int speedTurn = 80;

//variables pid
double kp = 0.175;
double kd = 0;
double setPoint;
float PID1;
double TICK_PID = 50;


#if !defined(CONFIG_BT_ENABLED) || !defined(CONFIG_BLUEDROID_ENABLED)
#error Bluetooth is not enabled! Please run `make menuconfig` to and enable it
#endif

BluetoothSerial SerialBT;

//instancio los objetos
Engine *engineRigh = new  Engine(PIN_ENGINE_MR1, PIN_ENGINE_MR2);
Engine *engineLeft = new Engine(PIN_ENGINE_ML1, PIN_ENGINE_ML2);

Button *start = new Button(PIN_BUTTON_START);

QRE1113 *endSensor = new QRE1113(PIN_END_SENSOR);

Sharp *SharpFront = new Sharp(PIN_SHARP_FRONT);
Sharp *SharpRigh = new Sharp(PIN_SHARP_RIGHT);
Sharp *SharpLeft = new Sharp(PIN_SHARP_LEFT);

Pid *engine = new Pid(kp, kd, setPoint, TICK_PID);

// funciones de los motores
void forward()
{
  engineRigh->SetSpeed(speedRight);
  engineLeft->SetSpeed(speedLeft);
  engineRigh->Forward();
  engineLeft->Forward();
}

void backward()
{
  engineRigh->SetSpeed(speedRight);
  engineLeft->SetSpeed(speedLeft);
  engineRigh->Backward();
  engineLeft->Backward();
}

void left()
{
  engineRigh->SetSpeed(speedRight);
  engineLeft->SetSpeed(speedLeft);
  engineRigh->Forward();
  engineLeft->Backward();
}

void right()
{
  engineRigh->SetSpeed(speedRight);
  engineLeft->SetSpeed(speedLeft);
  engineRigh->Backward();
  engineLeft->Forward();
}

void stop()
{
  engineRigh->SetSpeed(0);
  engineLeft->SetSpeed(0);
  engineRigh->Stop();
  engineLeft->Stop();
}

void turnRight()
{
  rightCont = 0;
  leftCont = 0;
  while(rightCont < TICK_TURN_RIGHT_90 || leftCont < TICK_TURN_RIGHT_90)
  {
    engineRigh->SetSpeed(speedTurn);
    engineLeft->SetSpeed(speedTurn);
    engineRigh->Backward();
    engineLeft->Forward();
  }
}

void turnLeft()
{
  rightCont = 0;
  leftCont = 0;
  while(rightCont < TICK_TURN_LEFT_90 || leftCont < TICK_TURN_LEFT_90)
  {
    engineRigh->SetSpeed(speedTurn);
    engineLeft->SetSpeed(speedTurn);
    engineRigh->Forward();
    engineLeft->Backward();
  }
}

void fulTurn()
{
  rightCont = 0;
  leftCont = 0;
  while(rightCont < TICK_TURN_180 || leftCont < TICK_TURN_180)
  {
    engineRigh->SetSpeed(speedTurn);
    engineLeft->SetSpeed(speedTurn);
    engineRigh->Forward();
    engineLeft->Backward();
  }
}

void antTurn()
{
  rightCont = 0;
  leftCont = 0;
  while(rightCont < TICK_ANT_TURN || leftCont < TICK_ANT_TURN)
  {
    engineRigh->SetSpeed(averageSpeed);
    engineLeft->SetSpeed(averageSpeed);
    engineRigh->Forward();
    engineLeft->Forward();
  }
}

void posTurn()
{
  rightCont = 0;
  leftCont = 0;
  while(rightCont < TICK_POST_TURN || leftCont < TICK_POST_TURN)
  {
    engineRigh->SetSpeed(averageSpeed);
    engineLeft->SetSpeed(averageSpeed);
    engineRigh->Forward();
    engineLeft->Forward();
  }
}

void ignoreTurn()
{
  rightCont = 0;
  leftCont = 0;
  while(rightCont < TICK_IGNORE_TURN || leftCont < TICK_IGNORE_TURN)
  {
    engineRigh->SetSpeed(averageSpeed);
    engineLeft->SetSpeed(averageSpeed);
    engineRigh->Forward();
    engineLeft->Forward();
  }
}

enum movement
{
  STANDBY,
  CONTINUE,
  STOP,
  RIGHT_TURN,
  LEFT_TURN,
  FULL_TURN,
  POST_TURN,
  IGNORE_TURN,
  ANT_TURN
};

int movement = STANDBY;

void movementLogic()
{
  switch (movement)
  {
  case STANDBY:
  {
    button_start = start->GetIsPress();
    if (button_start)
    {
      movement = CONTINUE;
    }

    stop();
    break;
  }

  case CONTINUE:
  {
    if (PID1)
    {
      if (PID1 > 30) PID1 = 30;
      if (PID1 < -30) PID1 = -30;

      speedRight = (averageSpeed - (PID1));
      speedLeft = (averageSpeed + (PID1));
    }
    forward();
    if (frontDistance < MAX_FRONT_DISTANCE) movement = STOP;
    if (leftDistance > MAX_SIDE_DISTANCE) movement = ANT_TURN;
    else if (rightDistance > MAX_SIDE_DISTANCE) movement = IGNORE_TURN;
    break;
  }

  case STOP:
  {
    stop();
    delay(100);
    if (rightDistance <= MAX_SIDE_DISTANCE && leftDistance > MAX_SIDE_DISTANCE) movement = LEFT_TURN;
    if (rightDistance >= MAX_SIDE_DISTANCE && leftDistance < MAX_SIDE_DISTANCE) movement = RIGHT_TURN;
    if (rightDistance >= MAX_SIDE_DISTANCE && leftDistance > MAX_SIDE_DISTANCE) movement = LEFT_TURN;
    if (rightDistance <= MAX_SIDE_DISTANCE && leftDistance < MAX_SIDE_DISTANCE) movement = FULL_TURN;
    break;
  }

  case RIGHT_TURN:
  {
    turnRight();
    movement = POST_TURN;
    break;
  }

  case LEFT_TURN:
  {
    turnLeft();
    movement = POST_TURN;
    break;
  }

  case FULL_TURN:
  {
    fulTurn();
    movement = POST_TURN;
    break;
  }

  case POST_TURN:
  {
    posTurn();
    movement = CONTINUE;
    break;
  }

  case ANT_TURN:
  {
    antTurn();
    movement = LEFT_TURN;
    break;
  }

  case IGNORE_TURN:
  {
    ignoreTurn();
    movement = CONTINUE;
    break;
  }
}
}


void printSensors()
{
  if (millis() > currentTimeDebugSensors + TICK_DEBUG)
  {
    currentTimeDebugSensors = millis();
    SerialBT.print("frontDistance: ");
    SerialBT.print(frontDistance);
    SerialBT.print(" || rightDistance: ");
    SerialBT.print(rightDistance);
    SerialBT.print(" || leftDistance: ");
    SerialBT.println(leftDistance);
  }
}

void printPID()
{
  if (millis() > currentTimeDebugPID + TICK_DEBUG)
  {
    currentTimeDebugPID = millis();
    SerialBT.print("PID: ");
    SerialBT.println(PID1);
    SerialBT.print("speedRight: ");
    SerialBT.print(speedRight);
    SerialBT.print(" || speedLeft: ");
    SerialBT.println(speedLeft);
  }
}
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

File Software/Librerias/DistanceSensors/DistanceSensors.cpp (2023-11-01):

#include "DistanceSensors.h"

float Isensor::AnalogReading(int pin)
{
    int n = 3;
    long sum = 0;
    for (int i = 0; i < n; i++)
    {
        sum = sum + analogRead(pin);
    }
    float adc = sum / n;
    return adc;
}

Sharp_GP2Y0A60S::Sharp_GP2Y0A60S(int pin)
{
    sensorPin = pin;
    pinMode(sensorPin, INPUT);
}

double Sharp_GP2Y0A60S::SensorRead()
{
    float adc = AnalogReading(sensorPin);
    double distance = 187754 * pow(adc, -1.183);
    return distance;
}

Sharp_GP2Y0A21::Sharp_GP2Y0A21(int pin)
{
    sensorPin = pin;
    pinMode(sensorPin, INPUT);
}

double Sharp_GP2Y0A21::SensorRead()
{
    long suma = 0;
    for (int i = 0; i < PROM; i++) // Realizo un promedio de "n" valores
    {
        suma = suma + analogRead(sensorPin);
    }
    float adc = suma / PROM;
    if(adc<400) adc=400;
    if(adc>4056) adc=4056;
    float distancia_cm = 11945.0 / (adc - 11.0); // hay que ajustar esta formula para que me devuelva bien la distancia
    return (distancia_cm);
    
}

Sharp_GP2Y0A02::Sharp_GP2Y0A02(int pin)
{
    sensorPin = pin;
    pinMode(sensorPin, INPUT);
}

double Sharp_GP2Y0A02::SensorRead()
{
    float adc = AnalogReading(sensorPin);
    if (adc > 2800 ) adc = 2800;
    if(adc < 300 ) adc = 300;
    float distance = 10650.08*(pow(adc , -0.74999))+1; //254000 *(pow( adc , -1.2134));
    return distance;
}

Ultrasound::Ultrasound(int trig, int echo)
{
    pinTrig = trig;
    pinEcho = echo;
    pinMode(pinEcho, INPUT);
    pinMode(pinTrig, OUTPUT);
    digitalWrite(pinTrig, LOW);
}

double Ultrasound::SensorRead()
{
    long distance;
    long pulse;
    // SENSOR
    digitalWrite(pinTrig, HIGH);
    delayMicroseconds(10); // Enviamos un pulso de 10us
    digitalWrite(pinTrig, LOW);
    pulse = pulseIn(pinEcho, HIGH);
    distance = pulse / 58.2;
    return distance;
}

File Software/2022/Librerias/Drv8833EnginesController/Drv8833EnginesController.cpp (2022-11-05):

#include "Drv8833EnginesController.h"

Engine::Engine(int in1, int in2)
{
    pin_in1 = in1;
    pin_in2 = in2;
    pinMode(pin_in1, OUTPUT);
    pinMode(pin_in2, OUTPUT);
}
void Engine::Forward(int pwm)
{
    speed = pwm;
    analogWrite(pin_in1, speed);
    analogWrite(pin_in2, 0);
}
void Engine::Backward(int pwm)
{
    speed = pwm;
    analogWrite(pin_in1, 0);
    analogWrite(pin_in2, speed);
}
void Engine::Stop()
{
    analogWrite(pin_in1, 0);
    analogWrite(pin_in2, 0);
}

EngineController::EngineController(int in1Right, int in2Right, int in1Left, int in2Left)
{
    pinIn1Right = in1Right;
    pinIn2Right = in2Right;
    pinIn1Left = in1Left;
    pinIn2Left = in2Left;
    engineRight = new Engine(pinIn1Right, pinIn2Right);
    engineLeft = new Engine(pinIn1Left, pinIn2Left);
}
void EngineController::Forward(int pwmRight, int pwmLeft)
{
    rightSpeed = pwmRight;
    leftSpeed = pwmLeft;
    engineRight->Forward(rightSpeed);
    engineLeft->Forward(leftSpeed);
}
void EngineController::Backward(int pwmRight, int pwmLeft)
{
    rightSpeed = pwmRight;
    leftSpeed = pwmLeft;
    engineRight->Backward(rightSpeed);
    engineLeft->Backward(leftSpeed);
}
void EngineController::Right(int pwmRight, int pwmLeft)
{
    rightSpeed = pwmRight;
    leftSpeed = pwmLeft;
    engineRight->Backward(rightSpeed);
    engineLeft->Forward(leftSpeed);
}
void EngineController::Left(int pwmRight, int pwmLeft)
{
    rightSpeed = pwmRight;
    leftSpeed = pwmLeft;
    engineRight->Forward(rightSpeed);
    engineLeft->Backward(leftSpeed);
}
void EngineController::Stop()
{
    engineRight->Stop();
    engineLeft->Stop();
}

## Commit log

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2022-08-27 Change of drivers and add encoder
    [BoverJR.csv, BoverJR.kicad_pcb, BoverJR.kicad_sch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]
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2022-08-28 sch listo se supone :)
    [BoverJR.csv, BoverJR.kicad_pcb, BoverJR.kicad_sch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]
2022-08-30 cambio de archivo kicad .pro hecho por taiel
    [BoverJR.csv, BoverJR.kicad_pcb, BoverJR.kicad_sch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]
2022-08-30 en correcion por bustos, ya casi
    [JRBover2.0.kicad_pcb, JRBover2.0.kicad_sch]
2022-08-31 el anterior tenia erro de antena esp32 , esta vez esta en la orilla espera correccion:)
    [JRBover2.0.kicad_pcb, JRBover2.0.kicad_sch]
2022-08-31 la perfeccione y le agregue Letra, no me hace la malla GND raro:)
    [JRBover2.0.kicad_pcb]
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2022-09-01 agregue class button y buzze y emepze maquian de estados
2022-09-01 realice cambios de pcb ddefinidos y cambios de Codigo POO
    [BoverJR.csv, BoverJR.kicad_pcb, BoverJR.kicad_sch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]
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2022-09-03 arregle el problema de la class motor y funciona de diego
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2022-09-05 Placa corregida por Bustos siuuuuuuuuuuuuuuuuuuuuuu
    [JRBover2.0.kicad_pcb]
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2022-09-08 correcion de error
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2022-09-16 arregle la libreria del encoder
    [BoverOriginVdef.ino]
2022-09-16 Agregue los diseños que usamos en la segunda fecha de LNR
    [Bover.SLDASM, BoverJR_LNR2_CHASIS.STL, ColumnaLaberinto.SLDPRT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]
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2022-10-07 Cambiios en los design
    [Bover.SLDASM, BoverJR_LNR2_CHASIS.STL, ColumnaLaberinto.SLDPRT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]
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2022-10-12 modificaciones a la placa
    [pcblaberinto jr.kicad_pcb, pcblaberinto jr.kicad_sch]
2022-10-12 cambios en la placa para que los corrija tashe
    [pcblaberinto jr.kicad_pcb, pcblaberinto jr.kicad_sch]
2022-10-12 agregando la placa de bover ORIGIN Y ORDENANDO UN POCO
    [JRBover2.0.kicad_pcb, JRBover2.0.kicad_sch, pcblaberinto jr.kicad_pcb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]
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2023-04-21 placa bover 2.0 terminada sin oled
    [BoverOrogin_V2.kicad_pcb, BoverOrogin_V2.kicad_sch]
2023-04-21 placa boverjr 2.0 termianada sin oled
    [Bover.SLDASM, BoverJR_LNR2_CHASIS.STL, BoverOrogin_V2.kicad_pcb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]
2023-04-24 placa bover terminada, sensores acomodados
    [BoverOrogin_V2.kicad_pcb, BoverOrogin_V2.kicad_sch]
2023-05-04 Agregue todas las carpetas que se habian borrado
    [BoverJr_V2.kicad_pcb, BoverJr_V2.kicad_sch, Bover_V2.kicad_pcb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]
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2023-05-16 SCH terminado y esperando alguna recomendacion
    [BoverJr_embebido.kicad_pcb, BoverJr_embebido.kicad_sch]
2023-05-31 Placa Flecha Verde terminada
    [BoverJr_embebido.kicad_pcb, BoverJr_embebido.kicad_sch]
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2023-05-31 cambie ordenes en el sch y agregue carpeta img
    [Flecha_Verde_V1.kicad_sch]
2023-05-31 buscando poner todo a 3.3v, y cambiando pines del esp32
    [Flecha_Verde_V1.kicad_sch]
2023-06-01 realice el sch del drv8833, me quedan dudas de pines la verdad
    [Flecha_Verde_V1.kicad_sch]
2023-06-01 PUSE PINES SON TODOS FLEXIBLES MENOS LA COMUNICACION I2C, ESTAN RECOMENDADOS Y SON LOS USADOS SIN PROBLEMAS
    [Flecha_Verde_V1.kicad_sch]
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2023-08-07 cambios finales en el esquematico de la version de bover para mandar a frabricar a china y comienzo del pcb
    [BoverJr_PCBWAY.kicad_pcb, BoverJr_PCBWAY.kicad_sch, BoverJr_V2.kicad_pcb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]
2023-08-08 Placa falta verificar sch nuevamente , el 3d y los empaquetados de componentes quevamos a usar
    [BoverJr_PCBWAY.kicad_pcb, BoverJr_PCBWAY.kicad_sch]
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2023-08-09 FALTA VER EL TEMA DE LOS MOTORES SI SE PUEDE ACHICAR, ACOMODAR SERIGRAFIA Y AÑADIR LOGOS Y VERIFICAR X 3D , Y VER SI PODEMOS PONER JST
    [BoverJr_PCBWAY.kicad_pcb, BoverJr_PCBWAY.kicad_sch]
2023-08-09 agregue logos , acomode serigrafia y componentes , agregue pads
    [BoverJr_PCBWAY.kicad_pcb, BoverJr_PCBWAY.kicad_sch]
2023-08-09 acomode pads y quedo casi lista falta verificar por 3d
    [BoverJr_PCBWAY.kicad_pcb]
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2023-08-10 Para mi esat lista , verificada por 3D y ezequiel, faltaria saber que dice bustos
    [BoverJr_PCBWAY.kicad_pcb, BoverJr_PCBWAY.kicad_sch]
2023-08-10 retoques en la seligrafia para que quede mejor
    [BoverJr_PCBWAY.kicad_pcb]
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2023-08-12 para mi ya esta listimisima, cambie sw y agregue jst , verifique serigrafia y 3d
    [BoverJr_PCBWAY.kicad_pcb, BoverJr_PCBWAY.kicad_sch]
2023-08-14 arreglos y consejos de bustos resueltos
    [BoverJr_PCBWAY.kicad_pcb, BoverJr_PCBWAY.kicad_sch]
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2023-08-16 agregue la placa de la mpu6050 y el esquematico del nuevo robot laberinto
    [BoverJr_PCBWAY-B_Cu.gbr, BoverJr_PCBWAY-B_Mask.gbr, BoverJr_PCBWAY-B_Paste.gbr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]
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2023-08-22 agrego carpeta sensores con sch de qre 1113
    [qre1113_modulo.kicad_pcb, qre1113_modulo.kicad_sch]
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2023-08-24 debo cambiar regulador ap21 3v3 por ams1117 3v3 lpm
    [Wakanda_MultiRobot.kicad_pcb, Wakanda_MultiRobot.kicad_sch]
2023-08-25 mejore y quedo listo para verificar wakanda multi
    [Driver_motores.kicad_sch, Wakanda_MultiRobot.kicad_pcb, Wakanda_MultiRobot.kicad_sch]
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2023-08-25 verifique por 3d , falta ver las vias para pads y eñ gerber y listo
    [Wakanda_MultiRobot.kicad_pcb, Wakanda_MultiRobot.kicad_sch]
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2023-08-28 Se crearon los archivos de la placa de sonseres qre1113 x8 y la de drivers TB67H451AFNG
    [Driver_TB67H451AFNG.kicad_pcb, Driver_TB67H451AFNG.kicad_sch, QRE1113_Line_Sensors_x8.kicad_pcb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]
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2023-08-28 complete pasta de soldado para pista de driver
    [Wakanda_MultiRobot.kicad_pcb]
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2023-08-30 esperando verificacion de pcbway ya cargue 6 gerber
    [BoverJr_PCBWAY-B_Cu.gbr, BoverJr_PCBWAY-B_Mask.gbr, BoverJr_PCBWAY-B_Paste.gbr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]
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2023-09-03 agrego cambios de gerber antes de fabricar que colgue
    [Wakanda_MultiRobot-B_Cu.gbr, Wakanda_MultiRobot-B_Mask.gbr, Wakanda_MultiRobot-B_Paste.gbr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]
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2023-11-02 gracias angel , faltaria ver de resetear Lectura para volverla a 0, y armar las demas giros
    [BoverJR_menu.ino]
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2023-11-03 falta resetear mpu despues de giros y porbar PID y otras cosas
    [BoverJR_menu.ino]
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2023-11-05 cambios pongo el mpuloop en el looop par a ver si sigue con errores
    [BoverJR_menu.ino]
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2023-11-09 PROBLEMAS DE IMU, PIDENTRA EN TODOS LOS CASOS AHORA
    [BoverJR_menu.ino]
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
